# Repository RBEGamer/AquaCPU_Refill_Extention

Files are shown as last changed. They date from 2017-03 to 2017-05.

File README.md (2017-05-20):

# WaterGuard
A automatic aquarium refiller with extra fallout detection.
This System fills a reserve Tank of your aquarium from a other watersource like a osmosis setup.
I used the system to fill automaticly the 4.5L tank of my RedSea Reefer Nano. Two water level sensors are installed in the tank so the system can check the water level and refill them from a watersource.

# FEATURES REFILL UNIT
* Automaitc refill of your tank
* Time failsafe
* Pump/Valve fail detection failsafe
* Esay Tank setup
* Sensor state failsafe
* FPGA based sensor state failsafe
* [OPTIONAL] CAN bus interface for interfacing with other AquaCPU Devices

# PARTS
* 2 Water level sensors for the refill tank (optical work best)
* 2 3D printed, water level sensor holders (See  http://www.thingiverse.com/thing:2218807)
* 1 Arduino Nano/Mini
* [OPTIONAL]  1 MCP2515 Can breakout board
* 1 Solid-State-Relais (or normal relais with transistor driver)
* 1 16x4 I2C Display (a 3d printed holder : http://www.thingiverse.com/thing:2218670)
* 1 Magnetic Valve 230V/12V
* 4 pusbuttons (with pull up resistors)
* 8 Luster Terminals
* 1 5V 2A Power Supply
* 1 ADS current sensor breakout

# SOFTWARE
* Download the Arduino-Sketch or the complete VS-Project
* Setup the pinconfig : 66-73
* Setup the invert setting : 74 - 75
* Setup the ACS712 sensor settings : 78
* Power all up and hold the config button to setup the other settings

# IMAGES
## Final simple case
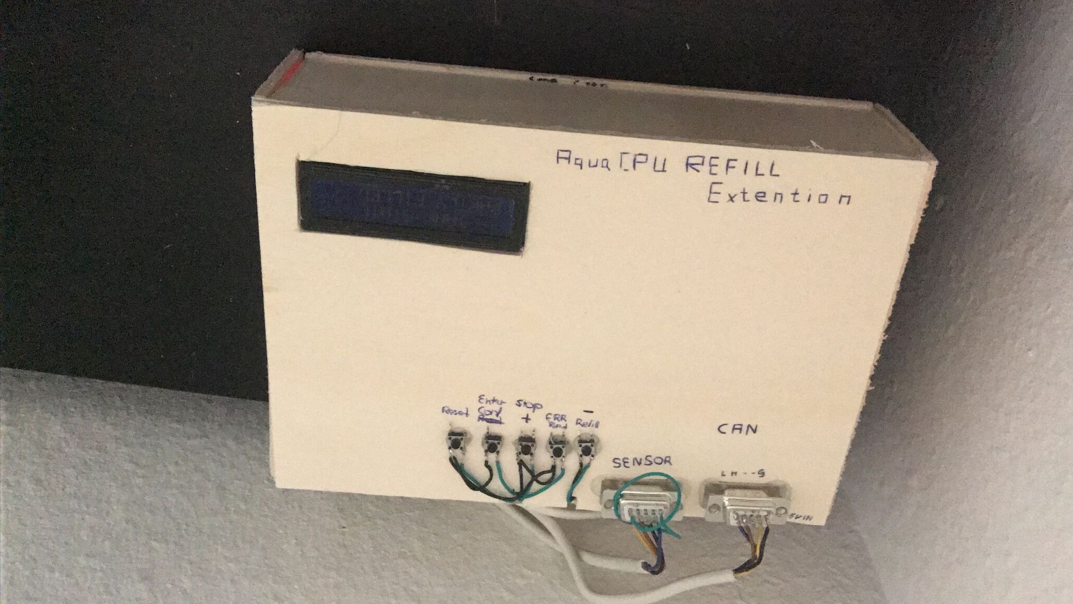
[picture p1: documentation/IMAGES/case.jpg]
Gopher image

## Final Hardware setup (glued on wood for testing)
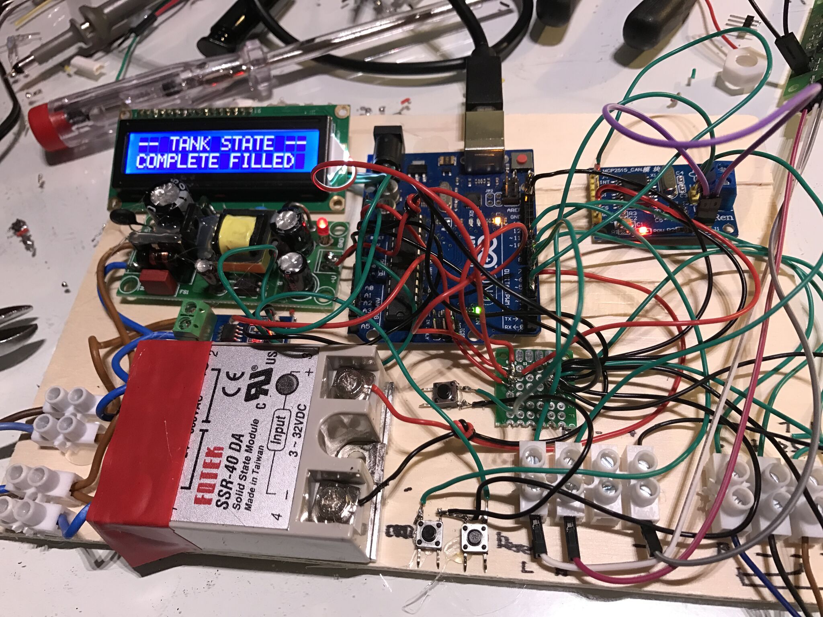
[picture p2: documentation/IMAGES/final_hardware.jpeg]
Gopher image


## Water level sensors, mounted on the reserve water tank
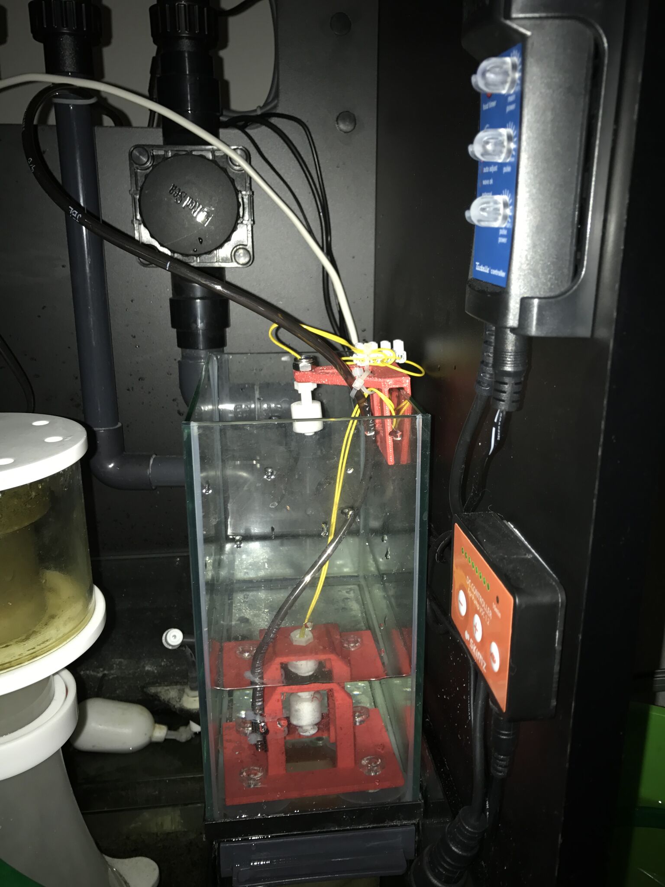
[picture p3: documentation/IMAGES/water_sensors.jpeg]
Gopher image


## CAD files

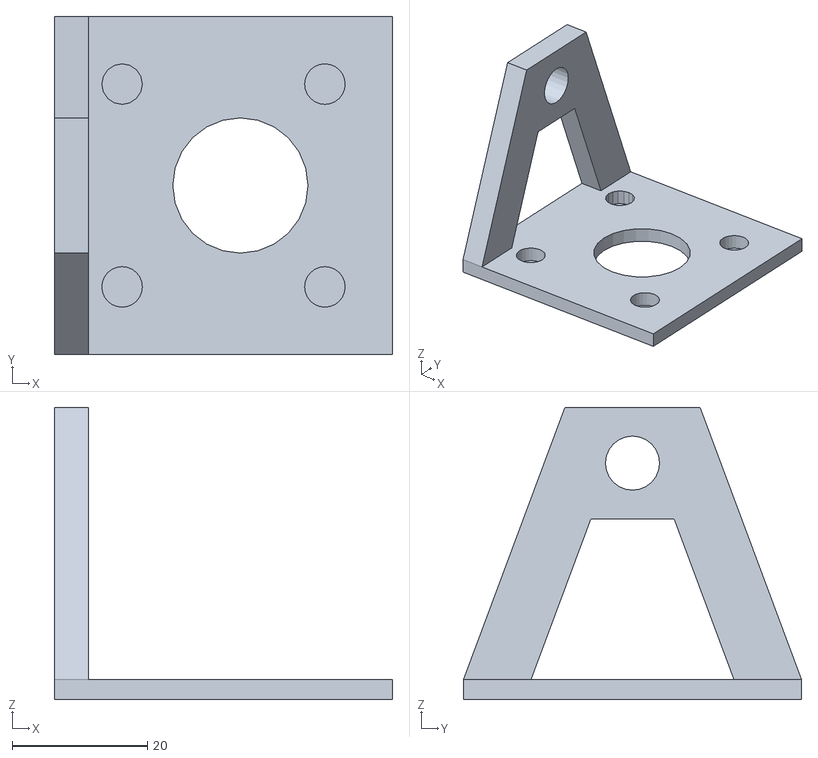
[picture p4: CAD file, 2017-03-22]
src/3d_print/stl/water_level_sensor_save_filament.stl
50.0 x 50.0 x 43.2

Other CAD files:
src/3d_print/stl/water_level_sensor.stl
src/3d_print/sketchup/water_level_sensor_save_filament~.skp
src/3d_print/sketchup/water_sensor_bottom_mount/water_sensor_bottom_mount.skp
src/3d_print/sketchup/water_sensor_top_mount/water_level_sensor_holder_top.skp
src/3d_print/sketchup/water_sensor_wall_mount/water_level_sensor.skp
src/3d_print/sketchup/water_sensor_wall_mount/water_level_sensor_save_filament.skp

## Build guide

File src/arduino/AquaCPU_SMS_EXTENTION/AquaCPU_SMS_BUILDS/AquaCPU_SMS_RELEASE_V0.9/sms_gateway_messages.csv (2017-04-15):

# EXTENTION MESSAGE FILE [EXT_ID_TYPE | CAN_ID | VAL_TYPE | BYTE_ORDER(0=LITTE_ENDIAN | 1=BIG_ENDIAN) | MESSAGE_STRING]
# GENERAL MESSAGES
0 | 1 | 0 | 0 | FATAL DEVICE ERROR
0 | 2 | 0 | 0 | GENERAL STOP
0 | 3 | 1 | 0 | NEW DEVICE REGISTERES
# MESSAGES FOR THE REFILL EXTENTION
1 | 256 | 0 | 0 | REFILL STARTED
1 | 257 | 0 | 0 | REFILL STOP
1 | 259 | 0 | 0 | REFILL FINISH
# 1 | 261 | 2 | 0 | TIME FILL REM

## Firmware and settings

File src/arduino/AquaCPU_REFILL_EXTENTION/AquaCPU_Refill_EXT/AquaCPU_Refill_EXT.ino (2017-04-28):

/*AquaCPU - REFILL UNIT

   https://github.com/fdebrabander/Arduino-LiquidCrystal-I2C-library
   ACS712 CODE http://blog.thesen.eu
*/

#define VERSION "1.0a"
#define EXTENTION_ID_TYPE_BYTE 1



#if EXTENTION_ID_TYPE_BYTE == 0
#error"BLA"
#endif
#include <EEPROM.h>
#include <Wire.h>
#include <LiquidCrystal_I2C.h>
#include <mcp_can.h>
#include <SPI.h>

union long_conv {
	char myByte[4];
	long mylong;
};
union float_conv
{
	char myByte[3];
	float myfloat;
};
union int_conv
{
	char myByte[2];
	int myInt;
};


MCP_CAN CAN0(10);     // Set CS to pin 10
bool CAN_SETUP_SUCC = false;
#define CAN_SPEED CAN_100KBPS
#define MCP_CRYSTAL_SPEED MCP_16MHZ
#define CAN0_INT 2
long unsigned int rxId;
unsigned char len = 0;
unsigned char rxBuf[8];
char msgString[128];
#define CAN_BUS_ID_GENERAL_ERR 0x001
#define CAN_BUS_ID_GENERAL_STOP 0x002
#define CAN_BUS_ID_GENERAL_REGISTER_ID 0x003
// REFILL EXTENTION SPCIFIC CAN IDs
#define CAN_BUS_ID_REFILL_STARTED 0x100
#define CAN_BUS_ID_REFILL_STOP 0x101
#define CAN_BUS_ID_MANUAL_REFILL 0x102
#define CAN_BUS_ID_REFILL_FINISH 0x103
#define CAN_BUS_TANK_STATE 0x104
#define CAN_BUS_ID_REFILL_UPDATE_TIME_REMEANING 0x105 
#define CAN_BUS_ID_AUTO_OFF_TIME_SEC 0x106
#define CAN_BUS_ID_TANK_SIZE 0x107
#define CAN_BUS_ID_REFILL_FLOW_RATE 0x108
#define CAN_BUS_ID_CURRENT 0x109

//TANK SETTINGS
float WATER_FLOW_RATE_ML_S = 2.0f; //IN ML PER SECOND
float WATER_REFILL_TANK_SIZE_L = 4.5f; // MLiter
float WATER_REFILL_TANK_SIZE_MULTIPLIER = 1.05f;
//PIN SETTINGS
#define LEVEL_SENSOR_BOTTOM_PIN 6
#define LEVEL_SENSOR_TOP_PIN 7
#define ERROR_RESET_PIN 8
#define PART_FILLED_PIN 4
#define VALVE_PIN 3
#define NOT_OFF_PIN 5
#define CONFIG_MODE_PIN A3
//PIN INVERT SETTINGS
#define INVERT_LEVEL_SENSOR_BOTTOM
#define INVERT_LEVEL_SENSOR_TOP
//#define INVERT_VALVE_STATE
//VALVE SETTINGS
float AUTO_OFF_CURRENT_MIDDLE = 10.0f; //WATT Alles als Stromverbrauch unter 10 Watt wird als error ausgeben
//SENSOR SETTINGS
#define ACS712_30A //#define ACS712_5A //#define ACS712_20A //please set this to you ACS model (5,20,30A)
//DISPLAY SETTINGS
#define ENABLE_I2C_DSIPLAY //if you have connect a 16x2 I2C Display
#define I2C_DISPLAY_ADDR 0x27 //set the I2C Adress of the display (eg use a i2c scanner)
//ERROR SETTINGS
#define ENABLE_ERROR_MANUAL_RESET //if you enable this you have to reset the system with the FIX ERROR BUTTON


bool NOT_FIXABLE_ERROR = false;
//SENSOR VARS
bool state_water_level_bottom_sensor = false;
bool state_water_level_top_sensor = false;
//DISPLAY VARS
#ifdef ENABLE_I2C_DSIPLAY
LiquidCrystal_I2C lcd(I2C_DISPLAY_ADDR, 16, 2);
uint8_t i2c_display_cross[8] = { 0x0, 0x1b, 0xe, 0x4, 0xe, 0x1b, 0x0 };
#endif


//VALVE VARS
#define AUTO_OFF_CURRENT_MIDDLE_COUNT 3
unsigned long AUTO_OFF_TIME_IN_SEC = ((WATER_REFILL_TANK_SIZE_L*WATER_REFILL_TANK_SIZE_MULTIPLIER * 1000) / WATER_FLOW_RATE_ML_S);
bool valve_state = false;
float last_values_middle[AUTO_OFF_CURRENT_MIDDLE_COUNT] = { AUTO_OFF_CURRENT_MIDDLE };
int middle_counter = 0;
int middle_value_current = AUTO_OFF_CURRENT_MIDDLE * AUTO_OFF_CURRENT_MIDDLE_COUNT;
long on_time = 0;
unsigned long AUTO_OFF_TIMER_INTERVALL = AUTO_OFF_TIME_IN_SEC *1000; //
//ACS VARS
float gfLineVoltage = 235.0f;
// typical effective Voltage in Germany
#ifdef ACS712_20A
const float gfACS712_Factor = 50.0f;
#endif
#ifdef ACS712_30A
const float gfACS712_Factor = 75.76f;
#endif
#ifdef ACS712_5A
const float gfACS712_Factor = 27.03f;
#endif
unsigned long gulSamplePeriod_us = 100000;  // 100ms is 5 cycles at 50Hz and 6 cycles at 60Hz
int giADCOffset = 512;                      // initial digital zero of the arduino input from ACS712

static unsigned long lastmillis;
static unsigned long lastmillis_disp_refresh;
static unsigned long lastmillis_disp_light;
#define DISP_DISPLAY_REFRESH (4*1000)
#define DISP_DISPLAY_LIGHT (10*1000)
//#define _DEBUG_EEPROM_RESET


void send_can_message(int _id, float _val) {
	if (CAN_SETUP_SUCC) {
		return;
	}

	float_conv conv;
	conv.myfloat = _val;
	byte sndStat = CAN0.sendMsgBuf(_id, 0, 3, conv.myByte);
	if (sndStat == CAN_OK) {
		//   Serial.println("Message Sent Successfully!");
	}
	else {
		 Serial.println("Error Sending Message... float");
	}
}

void send_can_message(int _id, bool _val) {
	if (CAN_SETUP_SUCC) {
		return;
	}
	byte sndStat = 0;
	if (_val) {
		sndStat = CAN0.sendMsgBuf(_id, 0, 1, 0x01);
	}
	else {
		sndStat = CAN0.sendMsgBuf(_id, 0, 1, 0x00);
	}
	if (sndStat == CAN_OK) {
		//   Serial.println("Message Sent Successfully!");
	}
	else {
		Serial.println("Error Sending Message... bool");
	}
}

void send_can_message(int _id, int _val) {
	if (CAN_SETUP_SUCC) {
		return;
	}
	int_conv i;
	i.myInt = _val;
	byte sndStat = CAN0.sendMsgBuf(_id, 0, 2, i.myByte);
	if (sndStat == CAN_OK) {
		//   Serial.println("Message Sent Successfully!");
	}
	else {
		 Serial.println("Error Sending Message...int");
	}
}

void send_can_message(int _id, long _val) {
	if (CAN_SETUP_SUCC) {
		return;
	}
	long_conv dba;
	dba.mylong = _val;
	byte sndStat = CAN0.sendMsgBuf(_id, 0, 4, dba.myByte);
	if (sndStat == CAN_OK) {
		//  Serial.println("Message Sent Successfully!");
	}
	else {
		 Serial.println("Error Sending Message...long");
	}
}


//FUNC DESC 
void read_level_sensors();

void show_config_menu() {

	//ENTER CONFIG MODE
	if (digitalRead(CONFIG_MODE_PIN) == LOW) {
		Serial.println("ENTER_CONFIG_MODE = 1");
#ifdef ENABLE_I2C_DSIPLAY
		lcd.backlight();
		lastmillis_disp_light = millis();
		lcd.clear();
		lcd.home();
		lcd.print("----- INFO -----");
		lcd.setCursor(0, 1);
		lcd.print("ENTER CONFIG MODE");
#endif

		delay(1000);

		volatile bool in_conf_mode = true;
		volatile int men_pos = 0;
		while (in_conf_mode) {
			if (digitalRead(CONFIG_MODE_PIN) == LOW) {
				men_pos++;
			}
			if (men_pos == 5) {
				in_conf_mode = false;
				break;
			}



			if (men_pos == 0 && digitalRead(PART_FILLED_PIN) == HIGH && digitalRead(NOT_OFF_PIN) == LOW) {
				WATER_FLOW_RATE_ML_S += 0.1f;
			}
			else if (men_pos == 0 && digitalRead(PART_FILLED_PIN) == LOW && digitalRead(NOT_OFF_PIN) == HIGH) {
				WATER_FLOW_RATE_ML_S -= 0.1f;
			}
			if (men_pos == 1 && digitalRead(PART_FILLED_PIN) == HIGH && digitalRead(NOT_OFF_PIN) == LOW) {
				WATER_REFILL_TANK_SIZE_L += 0.1f;
			}
			else if (men_pos == 1 && digitalRead(PART_FILLED_PIN) == LOW && digitalRead(NOT_OFF_PIN) == HIGH) {
				WATER_REFILL_TANK_SIZE_L -= 0.1f;
			}

			if (men_pos == 2 && digitalRead(PART_FILLED_PIN) == HIGH && digitalRead(NOT_OFF_PIN) == LOW) {
				WATER_REFILL_TANK_SIZE_MULTIPLIER += 0.01f;
			}
			else if (men_pos == 2 && digitalRead(PART_FILLED_PIN) == LOW && digitalRead(NOT_OFF_PIN) == HIGH) {
				WATER_REFILL_TANK_SIZE_MULTIPLIER -= 0.01f;
			}


			if (men_pos == 3 && digitalRead(PART_FILLED_PIN) == HIGH && digitalRead(NOT_OFF_PIN) == LOW) {
				AUTO_OFF_CURRENT_MIDDLE += 1.0f;
			}
			else if (men_pos == 3 && digitalRead(PART_FILLED_PIN) == LOW && digitalRead(NOT_OFF_PIN) == HIGH) {
				AUTO_OFF_CURRENT_MIDDLE -= 1.0f;
			}

			if (WATER_FLOW_RATE_ML_S < 1.0f) {
				WATER_FLOW_RATE_ML_S = 1.0f;
			}
			if (WATER_REFILL_TANK_SIZE_L < 0.1f) {
				WATER_REFILL_TANK_SIZE_L = 0.1f;
			}
			if (WATER_REFILL_TANK_SIZE_MULTIPLIER < 0.8f) {
				WATER_REFILL_TANK_SIZE_MULTIPLIER = 0.8f;
			}
			if (AUTO_OFF_CURRENT_MIDDLE < 5.0f) {
				AUTO_OFF_CURRENT_MIDDLE = 5.0f;
			}


			if (men_pos == 0) {
#ifdef ENABLE_I2C_DSIPLAY
				lcd.backlight();
				lastmillis_disp_light = millis();
				lcd.clear();
				lcd.home();
				lcd.print("REFILL FLOW RATE");
				lcd.setCursor(0, 1);
				lcd.print("" + String(WATER_FLOW_RATE_ML_S) + " ML/S");
#endif
			}
			if (men_pos == 1) {
#ifdef ENABLE_I2C_DSIPLAY
				lcd.backlight();
				lastmillis_disp_light = millis();
				lcd.clear();
				lcd.home();
				lcd.print("REFILL TANK SIZE");
				lcd.setCursor(0, 1);
				lcd.print("" + String(WATER_REFILL_TANK_SIZE_L) + " L");
#endif
			}

			if (men_pos == 2) {
#ifdef ENABLE_I2C_DSIPLAY
				lcd.backlight();
				lastmillis_disp_light = millis();
				lcd.clear();
				lcd.home();
				lcd.print("TIME MULTIPLIER");
				lcd.setCursor(0, 1);
				lcd.print("" + String(WATER_REFILL_TANK_SIZE_MULTIPLIER) + " %");
#endif
			}

			if (men_pos == 3) {
#ifdef ENABLE_I2C_DSIPLAY
				lcd.backlight();
				lastmillis_disp_light = millis();
				lcd.clear();
				lcd.home();
				lcd.print("VALVE POWER CONS");
				lcd.setCursor(0, 1);
				lcd.print("" + String(AUTO_OFF_CURRENT_MIDDLE) + " Watt");
#endif
			}


			if (men_pos == 4) {
				read_level_sensors();
#ifdef ENABLE_I2C_DSIPLAY
				lcd.backlight();
				lastmillis_disp_light = millis();
				lcd.clear();
				lcd.home();
				lcd.print("SENSOR STATES");
				lcd.setCursor(0, 1);
				lcd.print("BOTTOM:" + String((byte)state_water_level_bottom_sensor) + " TOP" + String((byte)state_water_level_top_sensor));
#endif
			}


			delay(100);
		}
		//SAFE TO EEPROM
		int addr_put = 8;
		EEPROM.put(addr_put, WATER_FLOW_RATE_ML_S);
		addr_put += sizeof(WATER_FLOW_RATE_ML_S);
		EEPROM.put(addr_put, WATER_REFILL_TANK_SIZE_L);
		addr_put += sizeof(float);
		EEPROM.put(addr_put, WATER_REFILL_TANK_SIZE_MULTIPLIER);
		addr_put += sizeof(float);
		EEPROM.put(addr_put, AUTO_OFF_CURRENT_MIDDLE);
		addr_put += sizeof(float);
	}
}

void setup()
{
#ifdef ENABLE_I2C_DSIPLAY
	lcd.begin();
	lcd.backlight();
	lcd.clear();
	lcd.home();
#endif

#ifdef ENABLE_I2C_DSIPLAY
	lcd.backlight();
	lcd.createChar(0, i2c_display_cross);
	lcd.clear();
	lcd.home();
	lcd.print("AquaCPU-Refill");
	lcd.setCursor(0, 1);
	lcd.print("VERSION: " + String(VERSION));
	delay(1000);
#endif


	

	Serial.begin(115200);

	delay(100);

	//FAIL RESET SCHALTUNG
#ifdef ENABLE_ERROR_MANUAL_RESET
	EEPROM.begin();
#ifdef _DEBUG_EEPROM_RESET
	EEPROM.write(0, 0); //ERROR FLAG
#endif
	int ret = EEPROM.read(0);
	if (ret == 1) {
		Serial.println("ERR:" + String(ret));
		NOT_FIXABLE_ERROR = true;
	}
	else {
		NOT_FIXABLE_ERROR = false;
	}
	pinMode(ERROR_RESET_PIN, INPUT);
	digitalWrite(ERROR_RESET_PIN, HIGH);
	if (digitalRead(ERROR_RESET_PIN) == LOW && NOT_FIXABLE_ERROR) {
		NOT_FIXABLE_ERROR = false;
		EEPROM.write(0, 0);
	}
#else
	NOT_FIXABLE_ERROR = false;
#endif
#ifdef ENABLE_I2C_DSIPLAY
	if (NOT_FIXABLE_ERROR) {
		lcd.backlight();
		lcd.clear();
		lcd.home();
		lcd.println("ERR PLEASE PRESS");
#ifdef ENABLE_ERROR_MANUAL_RESET
		lcd.setCursor(0, 1);
		lcd.print("RESET + ERR_RES");
#endif
	}
#endif

	while (NOT_FIXABLE_ERROR) {
		delay(500);
		continue;
	}

	//SEND DEBUG OVER CAN
	//PIN SETUP
	pinMode(VALVE_PIN, OUTPUT);
	digitalWrite(VALVE_PIN, LOW);
	valve_state = false;
	pinMode(LEVEL_SENSOR_BOTTOM_PIN, INPUT);
	pinMode(LEVEL_SENSOR_TOP_PIN, INPUT);
	digitalWrite(LEVEL_SENSOR_TOP_PIN, HIGH);
	digitalWrite(LEVEL_SENSOR_BOTTOM_PIN, HIGH);
	bool state_water_level_bottom_sensor = false;
	bool state_water_level_top_sensor = false;

	pinMode(PART_FILLED_PIN, INPUT);
	digitalWrite(PART_FILLED_PIN, HIGH);
	pinMode(NOT_OFF_PIN, INPUT);
	digitalWrite(NOT_OFF_PIN, HIGH);
	pinMode(CONFIG_MODE_PIN, INPUT);
	digitalWrite(CONFIG_MODE_PIN, HIGH);



	//LOAD VALUES
	int addr_get = 8;
	EEPROM.get(addr_get, WATER_FLOW_RATE_ML_S);
	addr_get += sizeof(WATER_FLOW_RATE_ML_S);
	EEPROM.get(addr_get, WATER_REFILL_TANK_SIZE_L);
	addr_get += sizeof(WATER_REFILL_TANK_SIZE_L);
	EEPROM.get(addr_get, WATER_REFILL_TANK_SIZE_MULTIPLIER);
	addr_get += sizeof(WATER_REFILL_TANK_SIZE_MULTIPLIER);
	EEPROM.get(addr_get, AUTO_OFF_CURRENT_MIDDLE);
	addr_get += sizeof(AUTO_OFF_CURRENT_MIDDLE);

	show_config_menu();

	//CALC IMPORTANT VALUES AFTER LOAD
	AUTO_OFF_TIME_IN_SEC = ((WATER_REFILL_TANK_SIZE_L*WATER_REFILL_TANK_SIZE_MULTIPLIER * 1000) / WATER_FLOW_RATE_ML_S);
	AUTO_OFF_TIMER_INTERVALL = AUTO_OFF_TIME_IN_SEC *1000;
	middle_value_current = AUTO_OFF_CURRENT_MIDDLE * AUTO_OFF_CURRENT_MIDDLE_COUNT;



	//SETUP CAN
	bool CAN_SETUP_SUCC = false;
	pinMode(CAN0_INT, INPUT);

	if (CAN0.begin(MCP_ANY, CAN_SPEED, MCP_CRYSTAL_SPEED) == CAN_OK) {
		CAN_SETUP_SUCC = true;
		CAN0.setMode(MCP_NORMAL);

#ifdef ENABLE_I2C_DSIPLAY
		lcd.begin();
		lcd.backlight();
		lcd.createChar(0, i2c_display_cross);
		lcd.clear();
		lcd.home();
		lcd.print("CAN-BUS ENABLED");
		lcd.setCursor(0, 1);
		lcd.print("");
		delay(500);
#endif

	}
	else {
		CAN_SETUP_SUCC = false;
	}

	//SEND CAN SETUP MESSAGES
	send_can_message(CAN_BUS_ID_GENERAL_REGISTER_ID, (char)EXTENTION_ID_BYTE);

	//SEND REGISTER VALUES
	send_can_message(CAN_BUS_ID_AUTO_OFF_TIME_SEC, (long)AUTO_OFF_TIME_IN_SEC);
	send_can_message(CAN_BUS_ID_TANK_SIZE, WATER_REFILL_TANK_SIZE_L);
	send_can_message(CAN_BUS_ID_REFILL_FLOW_RATE, WATER_FLOW_RATE_ML_S);
	send_can_message(CAN_BUS_ID_CURRENT, AUTO_OFF_CURRENT_MIDDLE);



	Serial.println("-- AquaCPU - REFILL UNIT --");
	Serial.println("-- Version : " + String(VERSION) + " --");
	Serial.println("AUTO_OFF_TIMER = " + String(AUTO_OFF_TIME_IN_SEC));
	Serial.println("REFILL_TANK_SIZE = " + String(WATER_REFILL_TANK_SIZE_L));
	Serial.println("VALVE_MIN_WATT = " + String(AUTO_OFF_CURRENT_MIDDLE));
	Serial.println("WATER_FLOW_RATE = " + String(WATER_FLOW_RATE_ML_S));
	if (CAN_SETUP_SUCC) {
		Serial.println("CAN_BUS_INIT_ERROR = false");
	}
	else {
		Serial.println("CAN_BUS_INIT_ERROR = true");
	}
	//Read init sensor states
	read_level_sensors();
	delay(500);
	Serial.println("SETUP DONE");
}

void read_level_sensors() {
#ifdef INVERT_LEVEL_SENSOR_BOTTOM
	state_water_level_bottom_sensor = digitalRead(LEVEL_SENSOR_BOTTOM_PIN);
#else
	state_water_level_bottom_sensor = !digitalRead(LEVEL_SENSOR_BOTTOM_PIN);
#endif

#ifdef INVERT_LEVEL_SENSOR_TOP
	state_water_level_top_sensor = digitalRead(LEVEL_SENSOR_TOP_PIN);
#else
	state_water_level_top_sensor = !digitalRead(LEVEL_SENSOR_TOP_PIN);
#endif
}

void set_valve_state(bool _en) {
	valve_state = _en;
#ifdef INVERT_VALVE_STATE
	digitalWrite(VALVE_PIN, !_en);
#else
	digitalWrite(VALVE_PIN, _en);
#endif
}

void enable_auto_refill() {

#ifdef ENABLE_I2C_DSIPLAY
	lcd.backlight();
	lastmillis_disp_light = millis();
	lcd.clear();
	lcd.home();
	lcd.print("   RUN REFILL");
	lcd.setCursor(0, 1);
	lcd.print("REM TIME : ");
#endif


	for (int i = 0; i < AUTO_OFF_CURRENT_MIDDLE_COUNT; i++) {
		last_values_middle[i] = AUTO_OFF_CURRENT_MIDDLE;
	}
	send_can_message(CAN_BUS_ID_REFILL_STARTED, true);
	on_time = 0;
	middle_value_current = AUTO_OFF_CURRENT_MIDDLE;
	set_valve_state(true); //open valve
	lastmillis = millis();
}

void set_not_fixable_error(int _c = -1) {
	set_valve_state(false);
	NOT_FIXABLE_ERROR = true;
#ifdef ENABLE_ERROR_MANUAL_RESET
	EEPROM.write(0, 1);
#endif
	send_can_message(CAN_BUS_ID_GENERAL_ERR, true);

#ifdef ENABLE_I2C_DSIPLAY
	if (NOT_FIXABLE_ERROR) {
		lcd.backlight();
		lastmillis_disp_refresh = millis();
		lcd.clear();
		lcd.home();
		lcd.write(0);
		switch (_c) {
		case -1: lcd.print("UNKNOWN ERR"); break;
		case 0: lcd.print("SENSOR MISMATCH"); break;
		case 1: lcd.print("TIME OUT"); break;
		case 2: lcd.print("NO LOAD"); break;
		default: lcd.print("UNKNOWN ERR"); break;
		}
#ifdef ENABLE_ERROR_MANUAL_RESET
		lcd.setCursor(0, 1);
		lcd.print("RESET+ERR BTN");
#endif
	}
#endif
	send_can_message(CAN_BUS_ID_REFILL_STOP, true);
}

void loop()
{


	read_level_sensors();

	if (NOT_FIXABLE_ERROR) {
		Serial.println("ERR");
		set_valve_state(false);
		delay(500);
		return;
	}

	//STOP BUTTON
	if (digitalRead(NOT_OFF_PIN) == LOW) {
		if (valve_state) {
#ifdef ENABLE_I2C_DSIPLAY
			lcd.backlight();
			lastmillis_disp_light = millis();
			lcd.clear();
			lcd.home();
			lcd.print("----- INFO -----");
			lcd.setCursor(0, 1);
			lcd.print("CANCEL REFILL");
#endif
			send_can_message(CAN_BUS_ID_REFILL_STOP, true);
			send_can_message(CAN_BUS_ID_GENERAL_STOP, true);
		}
		set_valve_state(false);

	}

	//INVALID SENSOR STATE CHECK
	if (state_water_level_top_sensor == 0 && state_water_level_bottom_sensor == 1) {
		Serial.println("ERROR - INVALID SENSOR STATE - VALVE OFF");
		set_not_fixable_error(0);
	}

	//ENABLE BACKLIGHT ONLY
	if (digitalRead(CONFIG_MODE_PIN) == LOW || digitalRead(PART_FILLED_PIN) == LOW) {
		lcd.backlight();
		lastmillis_disp_light = millis();
	}

	//PARTLY REFILL BUTTON
	if (digitalRead(PART_FILLED_PIN) == LOW && !valve_state && state_water_level_top_sensor == 1 && state_water_level_bottom_sensor == 0) {
#ifdef ENABLE_I2C_DSIPLAY
		lcd.backlight();
		lastmillis_disp_light = millis();
		lcd.clear();
		lcd.home();
		lcd.print("----- INFO -----");
		lcd.setCursor(0, 1);
		lcd.print("MANUAL FILL");
#endif
		send_can_message(CAN_BUS_ID_MANUAL_REFILL, true);
		enable_auto_refill();
	}




	//IF REFILL IN PROGRESS
	if (valve_state) {
		lastmillis_disp_light = millis();
		//TANK FULL -> STOP REFIL CLOSE VALVE
		if (state_water_level_top_sensor == 0) {
			Serial.println("INFO - WATER TANK FULL - VALVE OFF");
#ifdef ENABLE_I2C_DSIPLAY
			lcd.backlight();
			lastmillis_disp_light = millis();
			lcd.clear();
			lcd.home();
			lcd.print("----- INFO -----");
			lcd.setCursor(0, 1);
			lcd.print("TANK COMPLETE FILLED");
#endif
			set_valve_state(false);
			send_can_message(CAN_BUS_ID_REFILL_FINISH, true);
		}

		//CHECK FOR FLOWING WATT
		last_values_middle[middle_counter++] = acs_measure_loop();
		middle_value_current = 0.0f;
		for (int i = 0; i < AUTO_OFF_CURRENT_MIDDLE_COUNT; i++) {
			middle_value_current += last_values_middle[i];
		}
		if (middle_counter >= AUTO_OFF_CURRENT_MIDDLE_COUNT) {
			middle_counter = 0;
		}
		//NO CHECK IF HIGHER THAN THE MIN AMP
		if (middle_value_current < AUTO_OFF_CURRENT_MIDDLE * AUTO_OFF_CURRENT_MIDDLE_COUNT || middle_value_current < 0.0f) {
			valve_state = false;
			digitalWrite(VALVE_PIN, valve_state);
			Serial.println("ERROR - VALVE UNDERCURRENT SENSE - VALVE OFF");
			set_not_fixable_error(2);
		}

		//CHECK TIME
		if (millis() - lastmillis > AUTO_OFF_TIMER_INTERVALL) {
			valve_state = false;
			digitalWrite(VALVE_PIN, valve_state);
			Serial.println("ERROR - VALVE TIMER OVERFLOW - VALVE OFF");
			set_not_fixable_error(1);
		}


		
		unsigned long tr = (AUTO_OFF_TIMER_INTERVALL - (millis() - lastmillis));
		send_can_message(CAN_BUS_ID_REFILL_UPDATE_TIME_REMEANING, (long)tr);
		//SHOW LEFT REFILL TIME (ESTIMATED)
#ifdef ENABLE_I2C_DSIPLAY
		if (!NOT_FIXABLE_ERROR) { 
		lcd.backlight();
		lastmillis_disp_light = millis();

		lcd.setCursor(9, 1);
		lcd.print(String((tr / 6000.0f)));
		delay(100);
		}
#endif
		delay(100);
	}
	else {
		//START REFILL PROCESS AT EMPTY SENSOR STATE
		if (state_water_level_top_sensor == 1 && state_water_level_bottom_sensor == 1) {
			Serial.println("INFO - WATER TANK EMPTY - VALVE ON");
#ifdef ENABLE_I2C_DSIPLAY
			if (!NOT_FIXABLE_ERROR) {
				lcd.backlight();
				lastmillis_disp_light = millis();
				lcd.clear();
				lcd.home();
				lcd.print("  TANK REFILL  ");
				lcd.setCursor(0, 1);
				lcd.print("STARTED");
				delay(2000);
			}
#endif
			if (!NOT_FIXABLE_ERROR) {
				enable_auto_refill();
			}
		}


		//SHOW TANK FILL STATE AT IDLE, NO FILL JUST FOR INFO
#ifdef ENABLE_I2C_DSIPLAY
		if (millis() - lastmillis_disp_refresh > DISP_DISPLAY_REFRESH) {
			lastmillis_disp_refresh = millis();
			lcd.clear();
			lcd.home();
			lcd.print("-- TANK STATE --");
			lcd.setCursor(0, 1);
			if (state_water_level_top_sensor == 0 && state_water_level_bottom_sensor == 0) {
				lcd.print("COMPLETE FILLED");
				send_can_message(CAN_BUS_TANK_STATE, (long)1);
			}
			else  if (state_water_level_top_sensor == 1 && state_water_level_bottom_sensor == 0) {
				lcd.print("PARTLY FILLED");
				send_can_message(CAN_BUS_TANK_STATE, (long)2);
			}
			else if (state_water_level_top_sensor == 1 && state_water_level_bottom_sensor == 1) {
				lcd.print("EMPTY");
				send_can_message(CAN_BUS_TANK_STATE, (long)3);
			}
			else {
				lcd.print("UNKNOWN STATE");
				send_can_message(CAN_BUS_TANK_STATE, (long)0);
			}
		}
#endif

	}
	//BACKLIGHT OFF TIMER
#ifdef ENABLE_I2C_DSIPLAY
	if (millis() - lastmillis_disp_light > DISP_DISPLAY_LIGHT) {
		lcd.noBacklight();
	}
#endif







}











float acs_measure_loop() {

	long lNoSamples = 0;
	long lCurrentSumSQ = 0;
	long lCurrentSum = 0;

	// set-up ADC
	ADCSRA = 0x87;  // turn on adc, adc-freq = 1/128 of CPU ; keep in min: adc converseion takes 13 ADC clock cycles
	ADMUX = 0x40;   // internal 5V reference

	// 1st sample is slower due to datasheet - so we spoil it
	ADCSRA |= (1 << ADSC);
	while (!(ADCSRA & 0x10));

	// sample loop - with inital parameters, we will get approx 800 values in 100ms
	unsigned long ulEndMicros = micros() + gulSamplePeriod_us;
	while (micros() < ulEndMicros)
	{
		// start sampling and wait for result
		ADCSRA |= (1 << ADSC);
		while (!(ADCSRA & 0x10));

		// make sure that we read ADCL 1st
		long lValue = ADCL;
		lValue += (ADCH << 8);
		lValue -= giADCOffset;

		lCurrentSum += lValue;
		lCurrentSumSQ += lValue * lValue;
		lNoSamples++;
	}

	// stop sampling
	ADCSRA = 0x00;

	if (lNoSamples > 0) // if no samples, micros did run over
	{
		// correct quadradic current sum for offset: Sum((i(t)+o)^2) = Sum(i(t)^2) + 2*o*Sum(i(t)) + o^2*NoSamples
		// sum should be zero as we have sampled 5 cycles at 50Hz (or 6 at 60Hz)
		float fOffset = (float)lCurrentSum / lNoSamples;
		lCurrentSumSQ -= 2 * fOffset * lCurrentSum + fOffset * fOffset * lNoSamples;
		if (lCurrentSumSQ < 0) {
			lCurrentSumSQ = 0; // avoid NaN due to round-off effects
		}

		float fCurrentRMS = sqrtf((float)lCurrentSumSQ / (float)lNoSamples) * gfACS712_Factor * gfLineVoltage / 1024;


		// correct offset for next round
		giADCOffset = (int)(giADCOffset + fOffset + 0.5f);
		return fCurrentRMS;
	}
}

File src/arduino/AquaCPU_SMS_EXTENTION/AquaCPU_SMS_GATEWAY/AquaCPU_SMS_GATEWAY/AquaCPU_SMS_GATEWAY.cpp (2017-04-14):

#include <iostream>


/*
RECIEVE CAN MESSAGES WITH A FILTER OR ALL


//DOWNLOAD FILTER FILE WITH DATATYPES
EINE CSV FILE FÜR JEDE EXTENTION MIT DEN MESSAGES



*/



/*
-> move simple logger to seperate class with singleton
->check at message file parsing the the string only contains numbers inkl dot not
*/


#define VERSION "0.9a"
#define PROGRAM_NAME "AquaCPU_SMS_GATEWAY"
#define AUTHOR "Marcel Ochsendorf"
#define AUTHOR_EMAIL "marcel.ochsendorf@gmail.com"
#define LICENCE "GNU V3"


#include <iostream>
#include <linux/can.h>
#include <linux/can/raw.h>
#include <endian.h>
#include <net/if.h>
#include <sys/ioctl.h>
#include <sys/socket.h>
#include <sys/types.h>
#include <unistd.h>
#include <chrono>
#include <iomanip>
#include <stdlib.h>
#include <thread>
#include <cerrno>
#include <csignal>
#include <cstdint>
#include <cstdio>
#include <fstream>
#include <sstream>
#include <string>
#include <string.h>
#include <cstring> //for strstr <3
#include <signal.h>   
#include <vector>
#include <fcntl.h>
#include <sys/ioctl.h>
#include <net/if.h>
#include <linux/can.h>
#include <linux/can/raw.h>
#include "serialib.h"
#include "ini_parser.hpp"
#include <wiringPi.h>


namespace simple_logger {

#define log_error(x) log(x,LOG_TYPE::ERROR)
#define log_info(x) log(x, LOG_TYPE::INFO);
#define log_warning(x) log(x, LOG_TYPE::WARNING);

	std::ofstream log_file;
	bool file_correct = false;

	enum LOG_TYPE
	{
		ERROR = 0,
		INFO = 1,
		WARNING = 2
	};
	bool start_logger(const char* _path) {
		log_file.open(_path, std::ios_base::app | std::ios_base::out);
		file_correct = log_file.good();
		log_file << "<b>------------------ START NEW LOG ------------------</b><br>" << "\n";
		log_file.flush();
		return file_correct;
	}

	void log(const std::string _reas, LOG_TYPE _type = LOG_TYPE::ERROR) {
		if (!file_correct) { return; }
		std::string log_entry = "";
		log_entry.append("->");
		switch (_type)
		{
		case LOG_TYPE::ERROR:log_entry.append("<b>ERROR</b>"); break;
		case LOG_TYPE::INFO:log_entry.append("INFO"); break;
		case LOG_TYPE::WARNING:log_entry.append("WARNING"); break;
		default:log_entry.append("<b>UNKNOWN_TYPE</b>"); break;
		}
		log_entry.append(" : ");
		log_entry.append(_reas);
		log_file << log_entry << "<br>\n";
		log_file.flush();
	}

	void stop_log() {
		if (!file_correct) { return; }
		log_file.close();
	}

}

enum ENDIANNESS
{
	LITTE = 0,
	BIG = 1
};
enum CAN_DATA_TYPES
{
	BOOL_1 = 0,
	INT_2 = 1,
	LONG_4 = 2,
	FLOAT_3 = 3,
};
struct CAN_MESSAGES_STRUCT
{
	long extention_id;
	long listen_can_id;
	CAN_DATA_TYPES type;
	std::string message;
	ENDIANNESS byte_order;

};

union DATA_UNION
{
	__u8 byt[8];
	float float_3;
	int int_2;
	long long_4;
	bool bool_1;

};



//holds a can fraem with converted datatype
struct CAN_PROCECCED_FRAME_STRUCT
{
	long can_id;
	DATA_UNION data;
	CAN_DATA_TYPES type;
};

struct UART_MESSAGES
{
	std::string to_send;
	std::string expected;
	bool send;
	bool noCR;
};
// ------------------ GLOBALS -------------------------------------

sig_atomic_t signaled = 0; //FOR SINAL HANDLING
std::vector<CAN_MESSAGES_STRUCT> listen_can_messages; //PARSED CAN LISTEN MESSAGES FORM  CSV FILE
int soc;
int read_can_port;
//UART
int uart0_filestream = -1;
serialib LS;                                                            // Object of the serialib class
int Ret;             //returns the recieved serial chars                                                   // Used for return values
char Buffer[128]; //for the serial recieve

std::vector<std::string> sms_messages;
// ------------------- END GLOBALS -------------------------------


//STRING HELPER FUNC
std::string RemoveChar(std::string _s, const char _c)
{
	std::string result;
	for (size_t i = 0; i < _s.size(); i++)
	{
		char currentChar = _s[i];
		if (currentChar != _c)
			result += currentChar;
	}
	return result;
}
int count_chars_in_string(const std::string& _s, const char _c) {
	int count = 0;
	for (int i = 0; i < _s.size(); i++)
		if (_s[i] == _c) count++;
	return count;
}
bool check_for_only_numbers(const std::string& s) {
	//	char* p;
	//	strtod(s.c_str(), &p);
	//	return *p == 0;
	// return !s.empty() && s.find_first_not_of("-.0123456789") == std::string::npos;
	return true;
}



//CAN FUNC

void process_can_frame(can_frame& _frame) {

	for (size_t i = 0; i < listen_can_messages.size(); i++)
	{
		if (_frame.can_id == listen_can_messages[i].listen_can_id) {
			std::cout << listen_can_messages[i].message << std::endl;
				sms_messages.push_back(listen_can_messages[i].message);
			DATA_UNION pdata;
			if (listen_can_messages[i].byte_order == ENDIANNESS::BIG) {
				pdata.byt[0] = _frame.data[7];
				pdata.byt[1] = _frame.data[6];
				pdata.byt[2] = _frame.data[5];
				pdata.byt[3] = _frame.data[4];
				pdata.byt[4] = _frame.data[3];
				pdata.byt[5] = _frame.data[2];
				pdata.byt[6] = _frame.data[1];
				pdata.byt[7] = _frame.data[0];
			}
			else {
				pdata.byt[0] = _frame.data[0];
				pdata.byt[1] = _frame.data[1];
				pdata.byt[2] = _frame.data[2];
				pdata.byt[3] = _frame.data[3];
				pdata.byt[4] = _frame.data[4];
				pdata.byt[5] = _frame.data[5];
				pdata.byt[6] = _frame.data[6];
				pdata.byt[7] = _frame.data[7];
			}




			switch (listen_can_messages[i].type)
			{
			case CAN_DATA_TYPES::BOOL_1:std::cout << pdata.bool_1 << std::endl; break;
			case CAN_DATA_TYPES::FLOAT_3:std::cout << pdata.float_3 << std::endl; break;
			case CAN_DATA_TYPES::INT_2:std::cout << pdata.int_2 << std::endl; break;
			case CAN_DATA_TYPES::LONG_4:std::cout << pdata.long_4 << std::endl; break;
			default:
				//TODO ADD SIMPLELOG MESSAGE
				break;
			}
			//TODO CONVERT
			int fif = 0;
		}
	}


}


int can_open_port(const char *port)
{
	struct ifreq ifr;
	struct sockaddr_can addr;
	/* open socket */
	soc = socket(PF_CAN, SOCK_RAW, CAN_RAW);
	if (soc < 0)
	{
		return (-1);
	}
	addr.can_family = AF_CAN;
	strcpy(ifr.ifr_name, port);
	if (ioctl(soc, SIOCGIFINDEX, &ifr) < 0)
	{
		return (-1);
	}
	addr.can_ifindex = ifr.ifr_ifindex;
	fcntl(soc, F_SETFL, O_NONBLOCK);
	if (bind(soc, (struct sockaddr *)&addr, sizeof(addr)) < 0)
	{
		return (-1);
	}
	return 0;
}
int can_send_port(struct can_frame *frame)
{
	int retval;
	retval = write(soc, frame, sizeof(struct can_frame));
	if (retval != sizeof(struct can_frame))
	{
		return (-1);
	}
	else
	{
		return (0);
	}
}
/* this is just an example, run in a thread */
void can_read_port()
{
	struct can_frame frame_rd;
	int recvbytes = 0;
	read_can_port = 1;
	//while (read_can_port)
	//	{
	struct timeval timeout = { 1, 0 };
	fd_set readSet;
	FD_ZERO(&readSet);
	FD_SET(soc, &readSet);
	if (select((soc + 1), &readSet, NULL, NULL, &timeout) >= 0)
	{
		if (!read_can_port)
		{
			//			break;
		}
		if (FD_ISSET(soc, &readSet))
		{
			recvbytes = read(soc, &frame_rd, sizeof(struct can_frame));
			if (recvbytes)
			{
				//	printf("dlc = %d, data = %s\n", frame_rd.can_dlc, frame_rd.data);
				process_can_frame(frame_rd);
			}
		}
		//}
	}
}
int can_close_port()
{
	close(soc);
	return 0;
}
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

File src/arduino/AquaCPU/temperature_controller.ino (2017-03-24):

/*
1wire eingang temeprature setzt

output setzten



*/
#define temp_control_ram_start_index 0
#define temp_control_max_temp 30
#define temp_control_min_temp 0
#define temp_control_default_temp 25
#define temp_control_default_hysterese 1 //zb 1 grad


#define temp_control_max_temp_controllers 8 //depend on the datatype
uint8_t current_temp_controllers = 0; 
struct temp_control_data{
  uint16_t current_temp;  
  uint16_t set_temp;  
  bool enabled;
  uint16_t output_channel_id;
};

temp_control_data temp_controllers[temp_control_max_temp_controllers];


void temp_control_setup(){
/**/  



  
}

void temp_control_update(){
  
  
  
  }

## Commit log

2017-03-15 added water level sensor sketchup
    [water_level_sensor.skp]
2017-03-15 added stl files
    [water_level_sensor.skp, water_level_sensor.stl, water_level_sensor_save_filament.skp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]
2017-03-22 fix stl ._.
    [water_level_sensor_save_filament.stl]
2017-03-24 added first arduino files
2017-03-26 added new sensor holder
    for top mounting
    [water_level_sensor.skp, water_level_sensor_holder_top.skp, water_level_sensor_save_filament.skp]
2017-03-26 added new bottom holder
    [water_level_sensor.skp, water_level_sensor_holder_top.skp, water_level_sensor_save_filament.skp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]
2017-04-05 added working refill extention
    missing can
    [AquaCPU_Refill_EXT.ino]
2017-04-06 working can bus version
2017-04-12 pre final refill code
    [sms_gateway_messages.csv]
2017-04-13 added CAN->SMS Gateway
    [sms_gateway_messages.csv]
2017-04-15 added stable release
    [sms_gateway_messages.csv]
